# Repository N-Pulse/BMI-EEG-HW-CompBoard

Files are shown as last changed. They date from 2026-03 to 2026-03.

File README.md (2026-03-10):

# EEG Headset Main Board

This repository contains the PCB design of the EEG main board, adapted from the EMG bracelet's main board, for signal acquisition.
Detailed description of the project can be found in the Documentation folder

This work is licensed under a <a rel="license" href="https://creativecommons.org/licenses/by/4.0/">Creative Commons Attribution 4.0 International License</a>.

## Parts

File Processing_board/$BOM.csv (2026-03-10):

Reference | Qty | Value | DNP | Exclude from Board | MANUFACTURER | Manufacturer_Part_Number | Link
AE1 | 1 | PCB_antenna |  | Exclure du PCB
AE2 | 1 | AMCA31-2R450G-S1F-T3 |  |  | ABRACON | AMCA31-2R450G-S1F-T3 | https://www.mouser.ch/ProductDetail/ABRACON/AMCA31-2R450G-S1F-T3?qs=AAveGqk956GLuOddQEK40Q%3D%3D
C1,C2,C28,C30,C40,C41,C42,C43,C45,C46,C47,C51 | 12 | 100nF |  |  | Samsung Electro-Mechanics | CL05B104KP5VPNC | https://eu.mouser.com/ProductDetail/Samsung-Electro-Mechanics/CL05B104KP5VPNC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
C3,C4 | 2 | 10pF |  |  | KYOCERA AVX | 0603ZC100KAT2A | https://www.mouser.ch/ProductDetail/KYOCERA-AVX/0603ZC100KAT2A?qs=jGANiKWBgcibzoGXAkKY5Q%3D%3D
C5,C13 | 2 | 100μF
C6,C12 | 2 | >10μF
C7,C8,C10,C14,C15,C16,C17,C18,C19,C20,C21,C22,C23,C24 | 14 | 1μF
C9,C11 | 2 | 0.1μF
C25,C26,C27,C56,C57,C58,C59,C60,C61,C62,C63,C64,C65,C66,C67,C68 | 16 | 10nF
C29,C31,C50,C52 | 4 | 10uF |  |  | Murata Electronics | GRM155R61A106ME11D | https://www.mouser.ch/ProductDetail/Murata-Electronics/GRM155R61A106ME11D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
C34 | 1 | 0.8pF |  |  | Murata Electronics | GRM1555C1HR80BA01D | https://www.mouser.ch/ProductDetail/Murata-Electronics/GRM1555C1HR80BA01D?qs=e%252BE4OD6MgMezPYPintwvrA%3D%3D
C35 | 1 | 0.3pF |  |  | Murata Electronics | GRM1555C1HR30WA01D | https://www.mouser.ch/ProductDetail/Murata-Electronics/GRM1555C1HR30WA01D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
C38 | 1 | 1.5pF |  |  | Walsin | 0402N1R5B100CT | https://www.mouser.ch/ProductDetail/Walsin/0402N1R5B100CT?qs=ZrPdAQfJ6DObCBhS8paADQ%3D%3D
C44 | 1 | 1uF |  |  | Samsung Electro-Mechanics | CL05A105KP5NNNC | https://www.mouser.ch/ProductDetail/Samsung-Electro-Mechanics/CL05A105KP5NNNC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
C48 | 1 | 470nF |  |  | KEMET | C0402C473K8RACAUTO7411 | https://www.mouser.ch/ProductDetail/KEMET/C0402C473K8RACAUTO7411?qs=sSYV1F9c5cEF%2FA7Et64KMA%3D%3D
C49 | 1 | 4.7uF |  |  | Murata Electronics | GRM155C61E475ME15D | https://www.digikey.ch/en/products/detail/murata-electronics/GRM155C61E475ME15D/16821133
C53,C54 | 2 | 27pF |  |  | KYOCERA AVX | 08055C270KAT2A | https://www.mouser.ch/ProductDetail/KYOCERA-AVX/08055C270KAT2A?qs=ykEKLGTiBcy%2FccVg1dGO5g%3D%3D
C55 | 1 | 220nF |  |  | Murata Electronics | GRT155R71A224KE01D | https://www.mouser.ch/ProductDetail/Murata-Electronics/GRT155R71A224KE01D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
C69 | 1 | 1nF
D1,D4,D5,D6 | 4 | IN_S42BT LED |  |  | Inolux | IN-S42BT5G | https://www.mouser.ch/ProductDetail/Inolux/IN-S42BT5G?qs=mAH9sUMRCttW6d2tLN392Q%3D%3D
D2,D3 | 2 | PMEG4030AEXE-QX |  |  | Nexperia | PMEG4030AEXE-QX | https://www.mouser.ch/ProductDetail/Nexperia/PMEG4030AEXE-QX?qs=olJun0bQHM9XKv%2FbcqOajw%3D%3D
FL1 | 1 | DLF162500LT-5028A1 |  |  | TDK | DLF162500LT-5028A1 | https://www.mouser.ch/ProductDetail/TDK/DLF162500LT-5028A1?qs=U%2FZX79kHR%2FlwIbAISCs3qA%3D%3D
H1,H2 | 2 | MountingHole |  | Exclure du PCB
J1,J2 | 2 | Conn_01x08_Pin
J3 | 1 | Conn_01x06_Pin
J4,J5,J8,J9 | 4 | Conn_01x03_Pin
J6 | 1 | Conn_01x02_Pin
J10 | 1 | CONMHF1-SMD-G-T |  |  | TE Connectivity / Linx Technologies | CONMHF1-SMD-G-T | https://www.mouser.ch/ProductDetail/TE-Connectivity-Linx-Technologies/CONMHF1-SMD-G-T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
J11 | 1 | USB4215-03-A_REVA |  |  | CGT | USB4215-03-A | https://www.mouser.ch/ProductDetail/GCT/USB4215-03-A?qs=IKkN%2F947nfBipec8wvDabA%3D%3D
J12 | 1 | Conn_01x02_Pin
JP1 | 1 | SolderJumper_2_Bridged
JP2 | 1 | SolderJumper_2_Open
L1 | 1 | 2.7nH |  |  | Murata Electronics | LQG15HS2N7S02D | https://www.mouser.ch/ProductDetail/Murata-Electronics/LQG15HS2N7S02D?qs=ctz47l0uL1AKrLI74yO5Qw%3D%3D
L2 | 1 | 3.9nH |  |  | TE Connectivity / Sigma Inductors | 36550402S3N9T | https://www.mouser.ch/ProductDetail/TE-Connectivity-Sigma-Inductors/36550402S3N9T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
L3 | 1 | 2.2uH |  |  | Wurth Elektronik | 74479774222 | https://www.mouser.ch/ProductDetail/Wurth-Elektronik/74479774222?qs=%252BUQ4csG8Rsd58%2FKCVoLnRw%3D%3D
Q1 | 1 | DMP3056LSS-13 |  |  | Diodes Incorporated | DMP3056LSS-13 | https://www.mouser.ch/ProductDetail/Diodes-Incorporated/DMP3056LSS-13?qs=oUsD4qhOtFyEnPLZKitYRA%3D%3D
Q2,Q3 | 2 | DMN66D0LT-7 |  |  | Diodes Incorporated | DMN66D0LT-7 | https://www.mouser.ch/ProductDetail/Diodes-Incorporated/DMN66D0LT-7?qs=ptj1V1atRApcnSIo%2FSL0QQ%3D%3D
R1,R2,R3,R4,R7,R8,R10,R14,R20 | 9 | 100R |  |  | KOA Speer | RK73B1ETTPD101J | https://www.mouser.ch/ProductDetail/KOA-Speer/RK73B1ETTPD101J?qs=7ZBenkSduJQ3N2lLjwh2jA%3D%3D
R5,R6,R9,R13,R17,R18,R19,R21 | 8 | 10k |  |  | Wurth Elektronik | 560112110020 | https://www.mouser.ch/ProductDetail/Wurth-Elektronik/560112110020?qs=mELouGlnn3fA8%252B%2F79%2FueqA%3D%3D
R11,R12,R22,R23,R24,R25,R26,R27,R28,R29,R30,R31,R32,R33,R34,R35,R36,R37 | 18 | 47kΩ
R15,R16 | 2 | 5.1k |  |  | YAGEO | AC0402JR-075K1L | https://www.mouser.ch/ProductDetail/YAGEO/AC0402JR-075K1L?qs=ygRr%2Ftkhtev1AbJgasJMAQ%3D%3D
R38 | 1 | 1MΩ
SW1,SW2 | 2 | TL3305BF100QG |  |  | E-Switch | TL3305BF100QG | https://www.mouser.ch/ProductDetail/E-Switch/TL3305BF100QG?qs=IKkN%2F947nfDIPwqPQja%252BvQ%3D%3D
TP2,TP11 | 2 | TestPoint |  | Exclure du PCB
TP9 | 1 | 5V |  | Exclure du PCB
TP10 | 1 | 5V- |  | Exclure du PCB
TP12,TP13 | 2 | PN5260 |  |  | Keystone | 5260 | https://www.mouser.ch/ProductDetail/Keystone-Electronics/5260?qs=W%2FMpXkg%252BdQ5ZyD03UfNp6A%3D%3D
U1 | 1 | STM32WBA63CIU6 |  |  | STMicroelectronics | STM32WBA63CIU6 | https://www.mouser.ch/ProductDetail/STMicroelectronics/STM32WBA63CIU6?qs=a2MtRaTmNORvrgIwkIejkg%3D%3D
U5 | 1 | LD1117S50TR_SOT223 |  |  | STMicroelectronics | LD1117S50TR | https://www.mouser.ch/ProductDetail/STMicroelectronics/LD1117S50TR?qs=eQN2Ig5lfEwsh0kTXN%2FkTg%3D%3D
U6 | 1 | LD1117S33TR_SOT223 |  |  | STMicroelectronics | LD1117S33TR | https://www.mouser.ch/ProductDetail/STMicroelectronics/LD1117S33TR?qs=edoyzKMbmhntQZx4BFmoqw%3D%3D
U8 | 1 | BGS13SN8E6327XTSA1 |  |  | Infineon Technologies | BGS13SN8E6327XTSA1 | https://www.mouser.ch/ProductDetail/Infineon-Technologies/BGS13SN8E6327XTSA1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
U9 | 1 | MCP2200-I_SO |  |  | Microchip Technology | MCP2200-I/SO | https://www.mouser.ch/ProductDetail/Microchip-Technology/MCP2200-I-SO?qs=kI7nsUnms46fN8L9VZlJCA%3D%3D
U10,U11 | 2 | ADS1299IPAG
XTAL1 | 1 | CX2016DB32000D0FLJCC |  |  | KYOCERA AVX | CX2016DB32000D0FLJCC | https://www.mouser.ch/ProductDetail/KYOCERA-AVX/CX2016DB32000D0FLJCC?qs=k8ubvZJoN9AkB0G5%2Fsjh3g%3D%3D
XTAL2 | 1 | ECS-120-18-5PX-CKM-TR |  |  | ECS | ECS-120-18-5PX-CKM-TR | https://www.mouser.ch/ProductDetail/ECS/ECS-120-18-5PX-CKM-TR?qs=7MVldsJ5UaxGiQ3V9H8iDw%3D%3D
C36,C37 | 2 | Unknown | DNP | Exclure du PCB
C39 | 1 | 1.5pF | DNP | Exclure du PCB

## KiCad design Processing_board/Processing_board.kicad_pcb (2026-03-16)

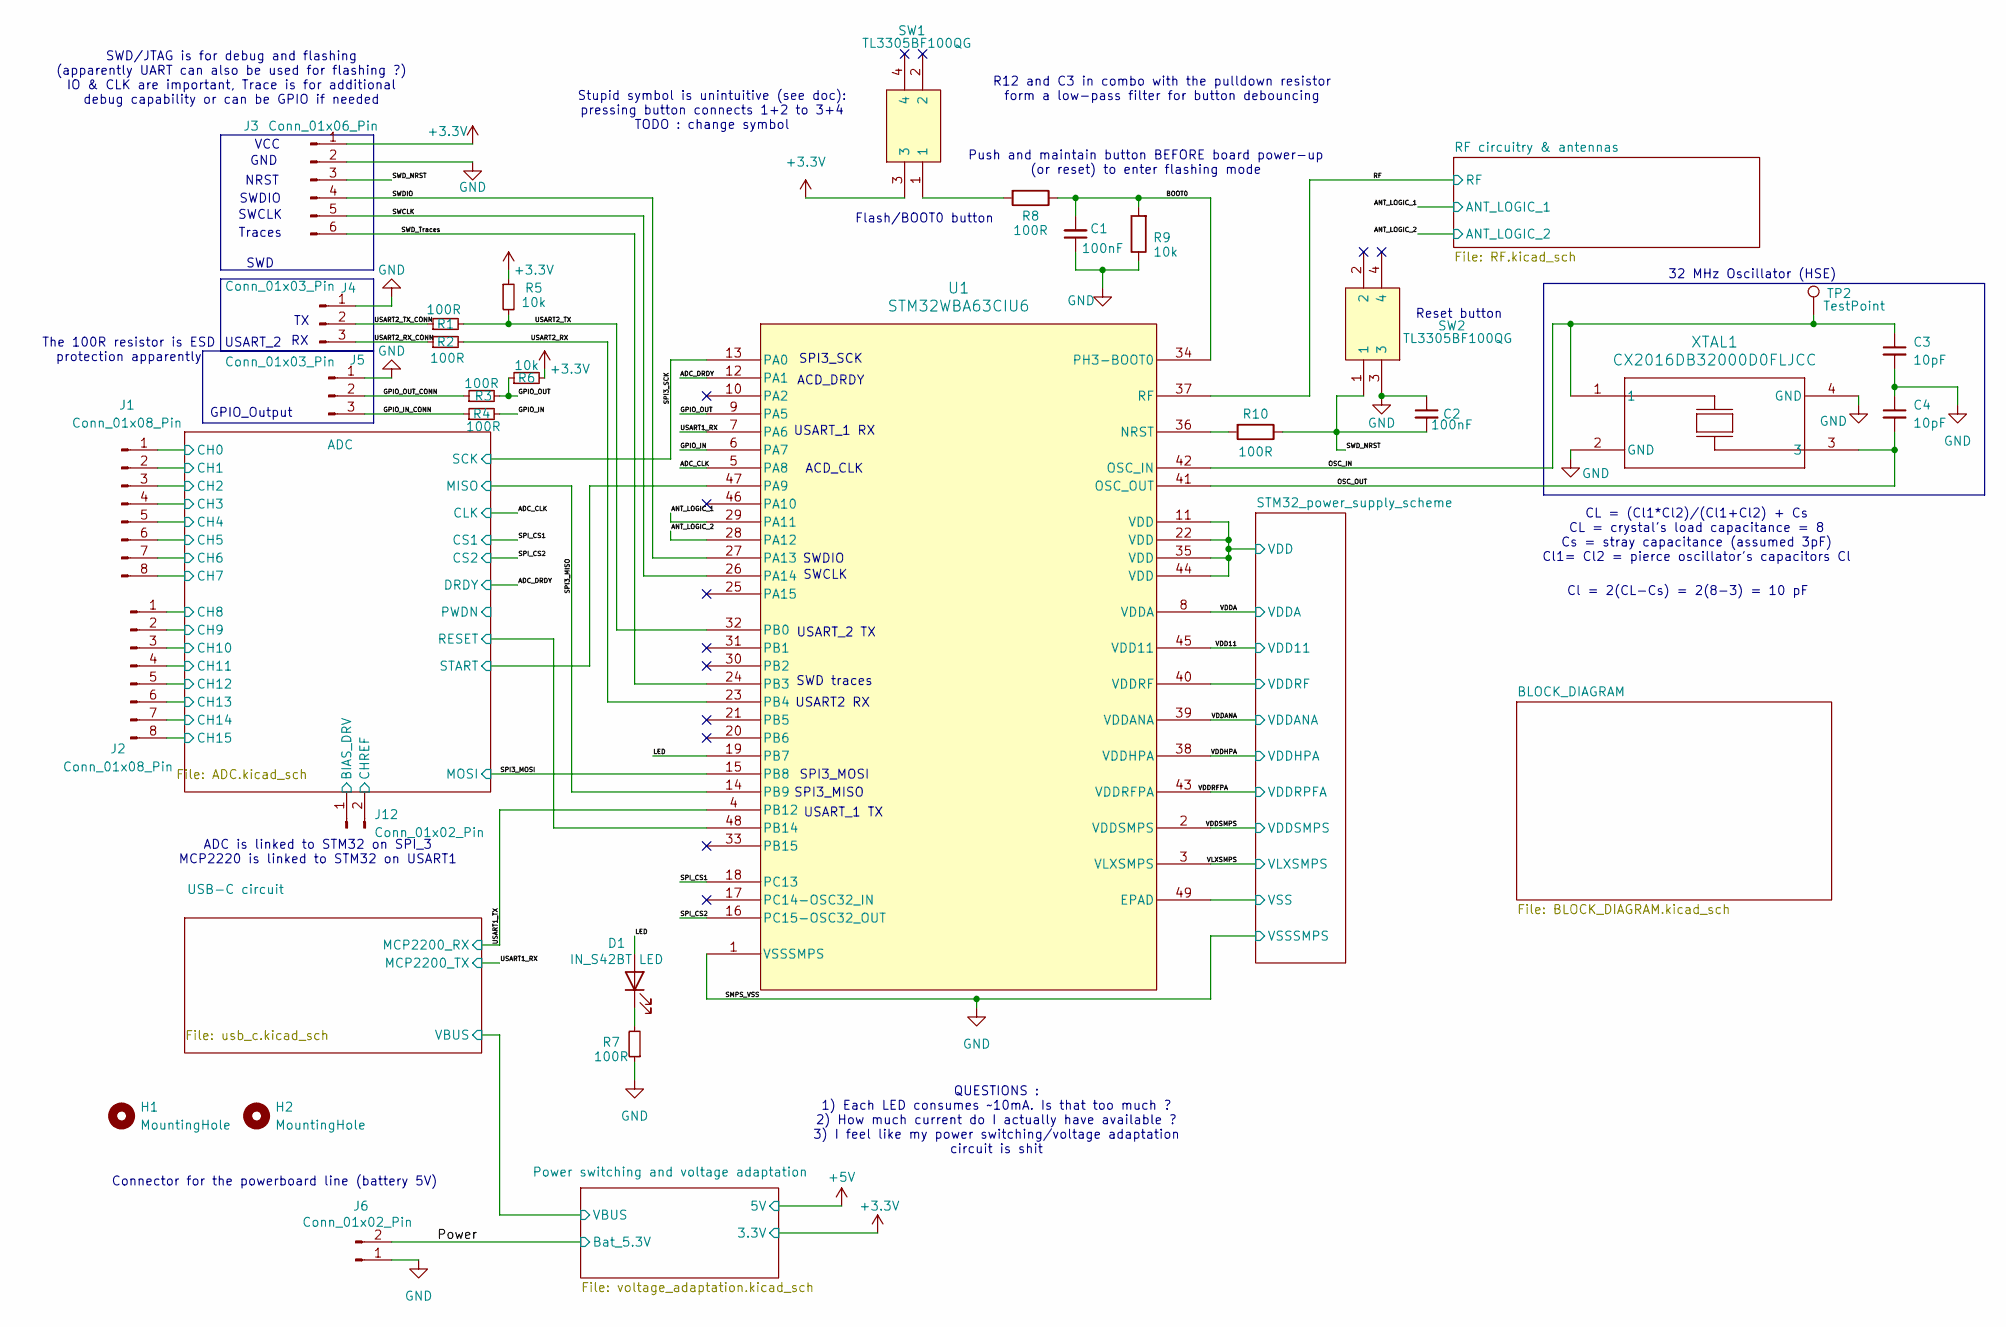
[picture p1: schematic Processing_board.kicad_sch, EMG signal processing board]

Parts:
C1, C2: 100nF; C_0201_0603Metric_Pad0.64x0.40mm_HandSolder; Manufacturer_Part_Number CL05B104KP5VPNC
C3, C4: 10pF; C_0201_0603Metric_Pad0.64x0.40mm_HandSolder; Manufacturer_Part_Number 0603ZC100KAT2A
D1: IN_S42BT LED; LED_0402_1005Metric; Manufacturer_Part_Number IN-S42BT5G
H1, H2: MountingHole; MountingHole_2.2mm_M2
J1, J2: Conn_01x08_Pin; PinSocket_1x08_P2.54mm_Vertical
J3: Conn_01x06_Pin; PinSocket_1x06_P2.54mm_Vertical
J4, J5: Conn_01x03_Pin; PinSocket_1x03_P2.54mm_Vertical
J6, J12: Conn_01x02_Pin; PinSocket_1x02_P2.54mm_Vertical
R1, R2, R3, R4, R7, R8, R10: 100R; R_0402_1005Metric; Manufacturer_Part_Number RK73B1ETTPD101J
R5, R6, R9: 10k; R_0402_1005Metric; Manufacturer_Part_Number 560112110020
SW1, SW2: TL3305BF100QG; TL3305BF160QG; Mouser Part Number 612-TL3305BF100QG
TP2: TestPoint; TestPoint_Pad_D1.0mm
U1: STM32WBA63CIU6; UFQFPN-48_STM; Manufacturer_Part_Number STM32WBA63CIU6
XTAL1: CX2016DB32000D0FLJCC; xtal4_CX2016DB_AVX; Manufacturer_Part_Number CX2016DB32000D0FLJCC

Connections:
+3.3V: J3.1, R5.1, R6.2, SW1.3, U1.2 (VDDSMPS), U1.8 (VDDA), U1.11 (VDD), U1.22 (VDD), U1.35 (VDD), U1.40 (VDDRF), U1.44 (VDD); also elsewhere on the board
/ADC/BIAS_DRV: J12.1; also elsewhere on the board
/ADC/IN1P: J1.1; also elsewhere on the board
/ADC/IN2P: J1.2; also elsewhere on the board
/ADC/IN3P: J1.3; also elsewhere on the board
/ADC/IN4P: J1.4; also elsewhere on the board
/ADC/IN5P: J1.5; also elsewhere on the board
/ADC/IN6P: J1.6; also elsewhere on the board
/ADC/IN7P: J1.7; also elsewhere on the board
/ADC/IN8P: J1.8; also elsewhere on the board
/ADC/IN9P: J2.1; also elsewhere on the board
/ADC/IN10P: J2.2; also elsewhere on the board
/ADC/IN11P: J2.3; also elsewhere on the board
/ADC/IN12P: J2.4; also elsewhere on the board
/ADC/IN13P: J2.5; also elsewhere on the board
/ADC/IN14P: J2.6; also elsewhere on the board
/ADC/IN15P: J2.7; also elsewhere on the board
/ADC/IN16P: J2.8; also elsewhere on the board
/ADC/RESET: U1.48 (PB14); also elsewhere on the board
/ADC/SRB1: J12.2; also elsewhere on the board
/ADC/START: U1.47 (PA9); also elsewhere on the board
/ADC_CLK: U1.5 (PA8); also elsewhere on the board
/ADC_DRDY: U1.12 (PA1); also elsewhere on the board
/ANT_LOGIC_1: U1.29 (PA11)
/ANT_LOGIC_2: U1.28 (PA12)
/BOOT0: C1.2, R8.1, R9.2, U1.34 (PH3-BOOT0)
/GPIO_IN: R4.2, U1.6 (PA7)
/GPIO_IN_CONN: J5.3, R4.1
/GPIO_OUT: R3.2, R6.1, U1.9 (PA5)
/GPIO_OUT_CONN: J5.2, R3.1
/LED: D1.2 (A), U1.19 (PB7)
/OSC_IN: C3.1, TP2.1, U1.42 (OSC_IN), XTAL1.1
/OSC_OUT: C4.2, U1.41 (OSC_OUT), XTAL1.3
/Power: J6.2; also elsewhere on the board
/RF: U1.37 (RF); also elsewhere on the board
/SPI3_MISO: U1.14 (PB9); also elsewhere on the board
/SPI3_MOSI: U1.15 (PB8); also elsewhere on the board
/SPI3_SCK: U1.13 (PA0); also elsewhere on the board
/SPI_CS1: U1.18 (PC13); also elsewhere on the board
/SPI_CS2: U1.16 (PC15-OSC32_OUT); also elsewhere on the board
/SWCLK: J3.5, U1.26 (PA14)
/SWDIO: J3.4, U1.27 (PA13)
/SWD_NRST: C2.2, J3.3, R10.1, SW2.1
/SWD_Traces: J3.6, U1.24 (PB3)
/USART1_RX: U1.7 (PA6); also elsewhere on the board
/USART1_TX: U1.4 (PB12); also elsewhere on the board
/USART2_RX: R2.2, U1.23 (PB4)
/USART2_RX_CONN: J4.3, R2.1
/USART2_TX: R1.2, R5.2, U1.32 (PB0)
/USART2_TX_CONN: J4.2, R1.1
/VDD11: U1.39 (VDDANA), U1.43 (VDDRFPA), U1.45 (VDD11); also elsewhere on the board
/VDDHPA: U1.38 (VDDHPA); also elsewhere on the board
/VLXSMPS: U1.3 (VLXSMPS); also elsewhere on the board
GND: C1.1, C2.1, C3.2, C4.1, J3.2, J4.1, J5.1, J6.1, R7.1, R9.1, SW2.3, U1.1 (VSSSMPS), U1.49 (EPAD), XTAL1.2 (GND), XTAL1.4 (GND); also elsewhere on the board
unnamed: D1.1 (K), R7.2
unnamed: R8.2, SW1.1
unnamed: R10.2, U1.36 (NRST)

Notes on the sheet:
USART_1 TX
SWD/JTAG is for debug and flashing (apparently UART can also be used for flashing ?) IO & CLK are important, Trace is for additional debug capability or can be GPIO if needed
SWD
VCC
SPI3_MISO
The 100R resistor is ESD protection apparently
Reset button
32 MHz Oscillator (HSE)
SWCLK
SPI3_MOSI
SPI3_SCK
Flash/BOOT0 button
CL = (Cl1*Cl2)/(Cl1+Cl2) + Cs CL = crystal's load capacitance = 8 Cs = stray capacitance (assumed 3pF) Cl1= Cl2 = pierce oscillator's capacitors Cl
Stupid symbol is unintuitive (see doc): pressing button connects 1+2 to 3+4 TODO : change symbol
Push and maintain button BEFORE board power-up (or reset) to enter flashing mode
NRST
SWDIO
ADC is linked to STM32 on SPI_3 MCP2220 is linked to STM32 on USART1
USART_2 TX
USART_2
ACD_DRDY
ACD_CLK
Traces
USART_1 RX
GPIO_Output
QUESTIONS : 1) Each LED consumes ~10mA. Is that too much ? 2) How much current do I actually have available ? 3) I feel like my power switching/voltage adaptation circuit is shit
USART2 RX
Cl = 2(CL-Cs) = 2(8-3) = 10 pF
GND
R12 and C3 in combo with the pulldown resistor form a low-pass filter for button debouncing
Connector for the powerboard line (battery 5V)
SWD traces

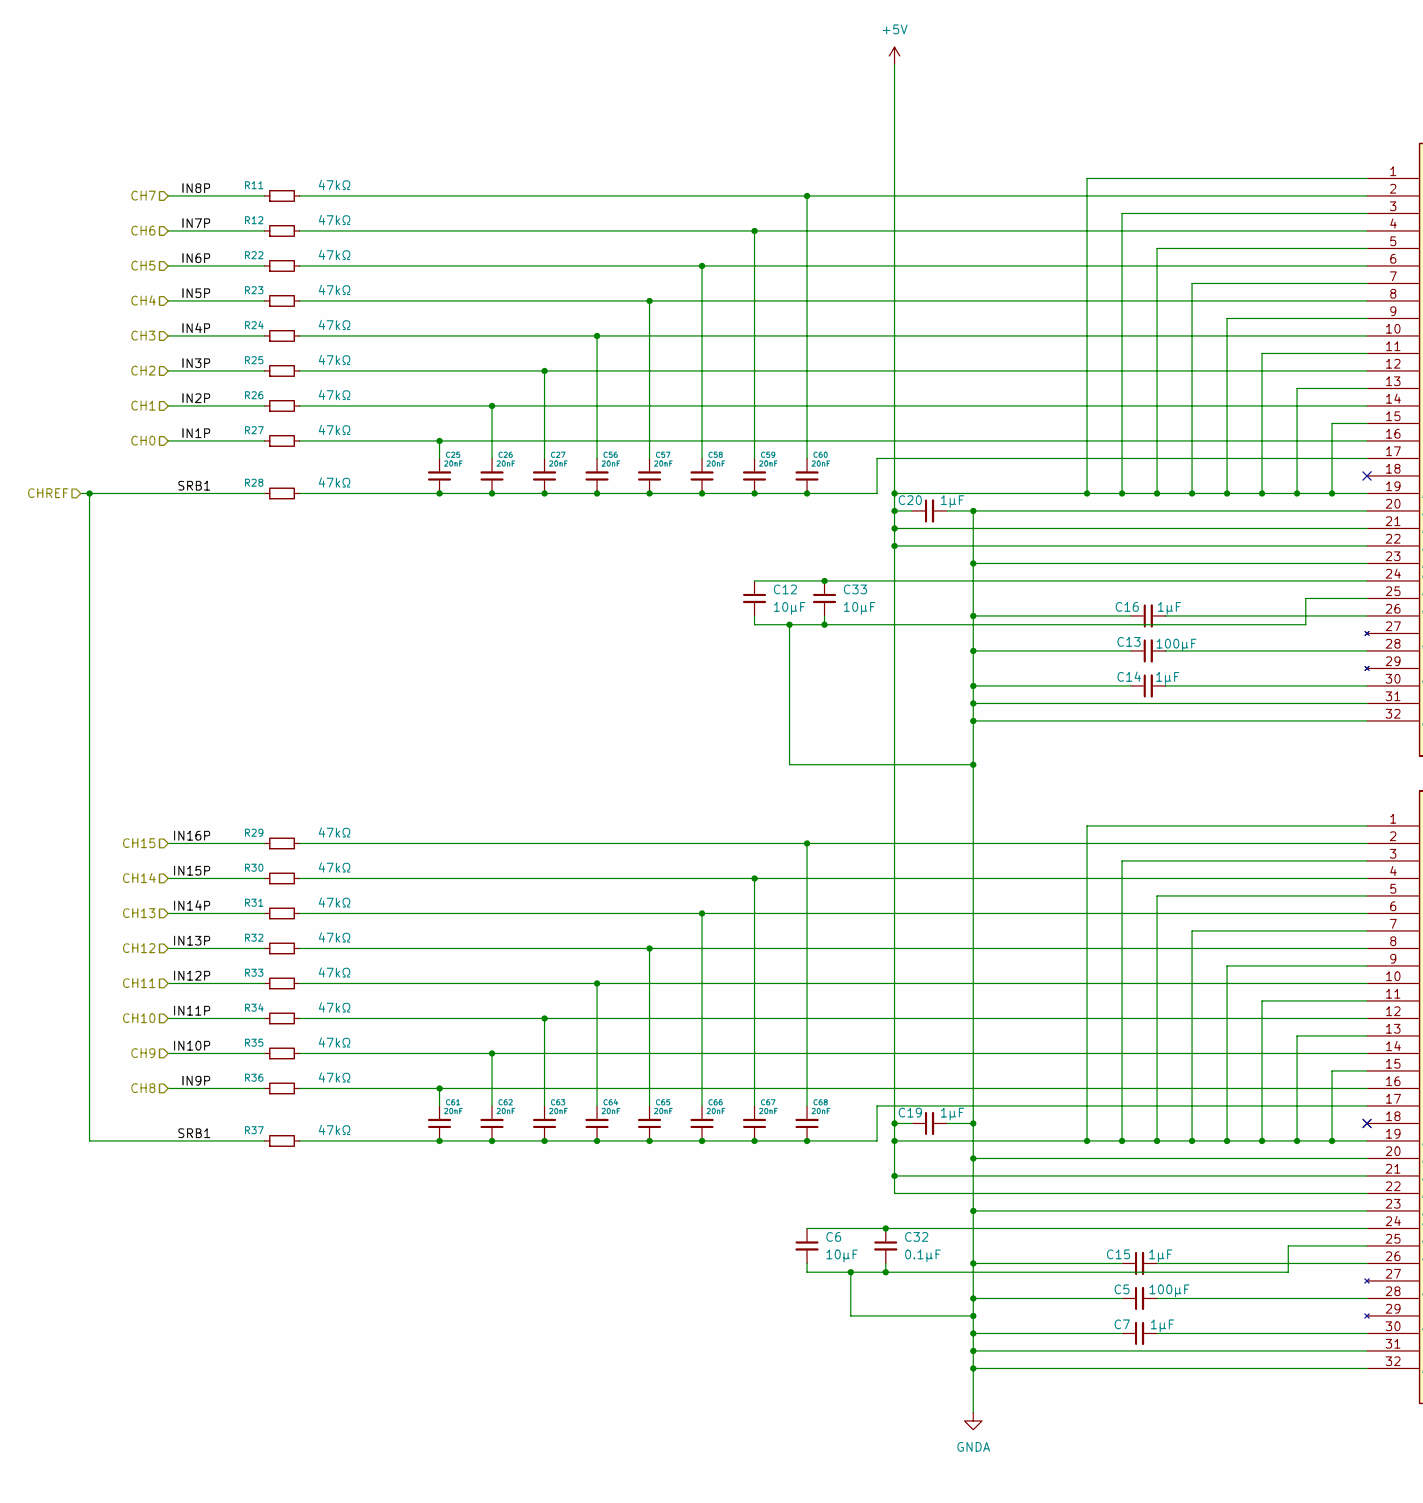
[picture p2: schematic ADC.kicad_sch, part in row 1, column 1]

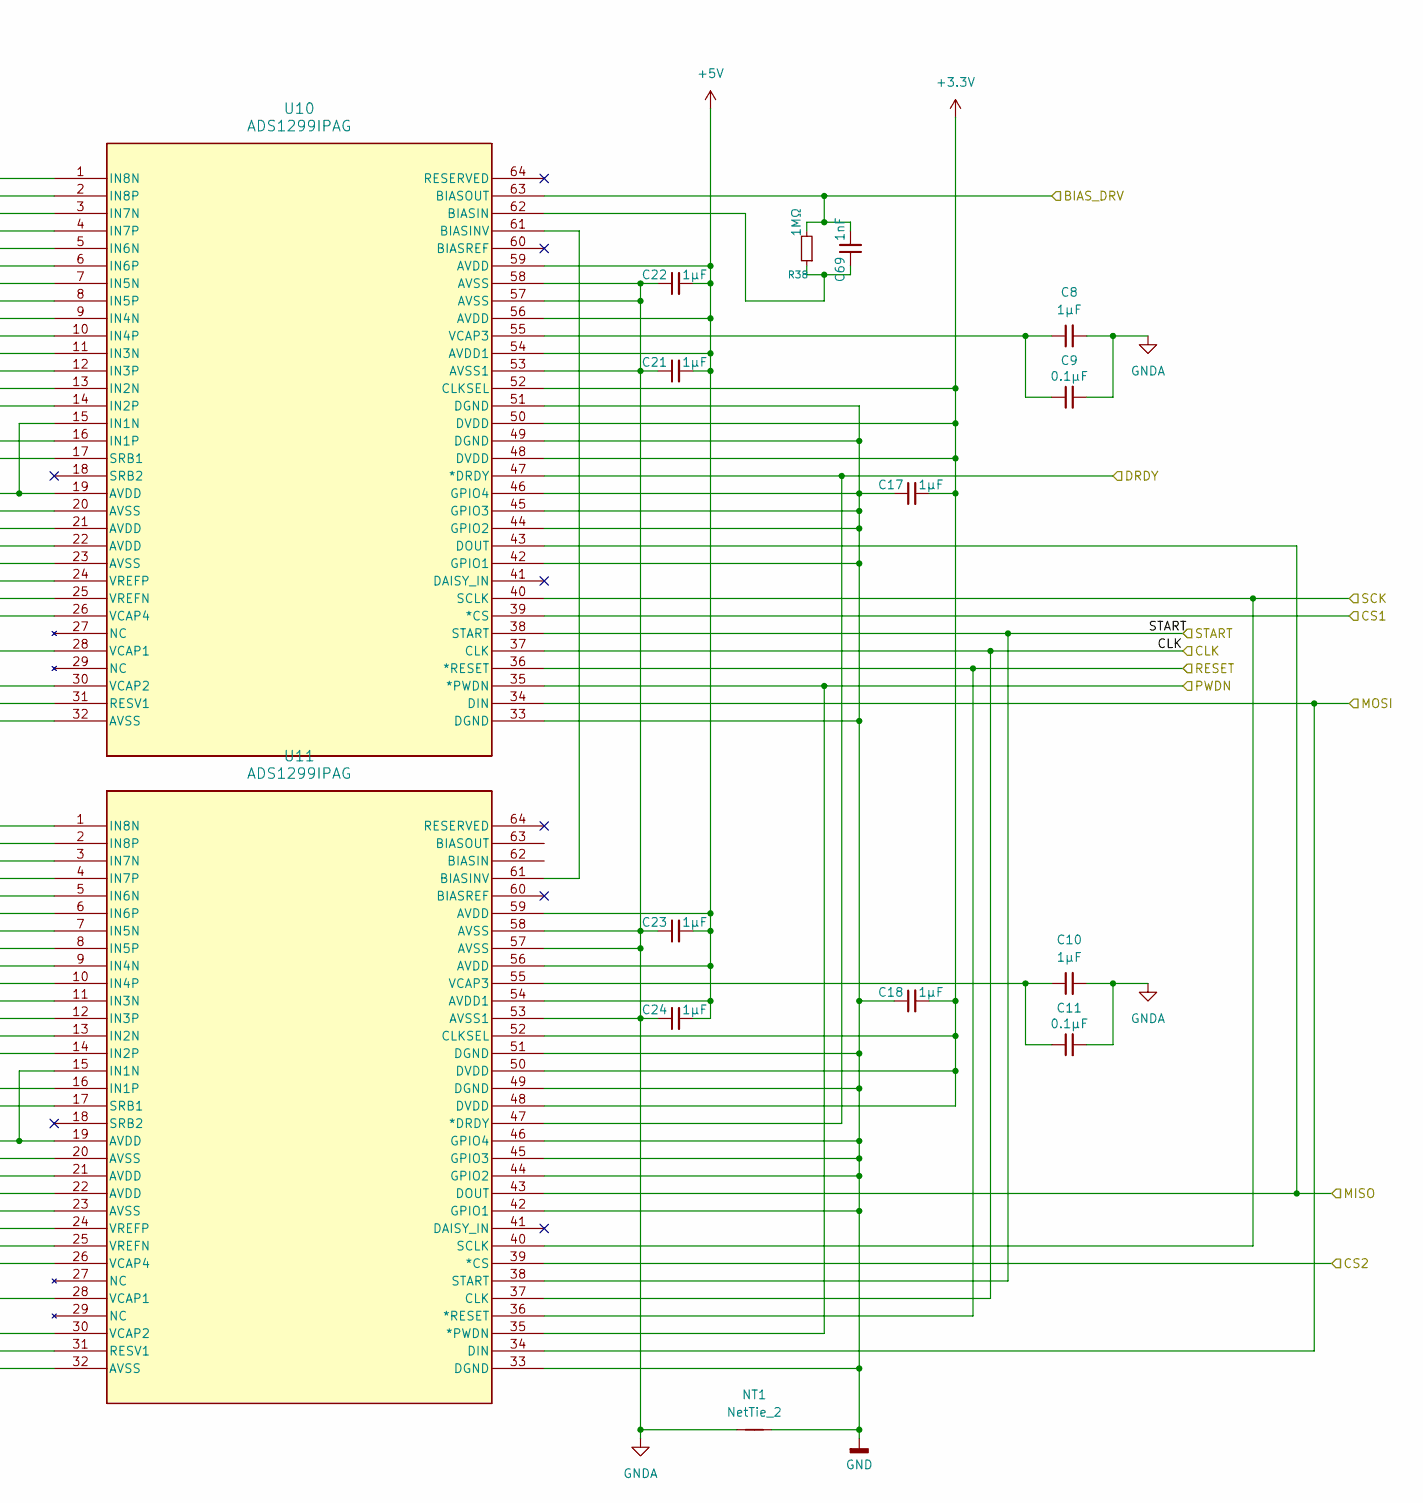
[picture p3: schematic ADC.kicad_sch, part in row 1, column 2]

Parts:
C5, C13: 100μF; C_1210_3225Metric
C6, C12, C33: 10μF; C_0805_2012Metric
C7, C8, C10, C14, C15, C16, C17, C18, C19, C20, C21, C22, C23, C24: 1μF; C_0805_2012Metric
C9, C11: 0.1μF; C_0603_1608Metric
C25, C26, C27, C56, C57, C58, C59, C60, C61, C62, C63, C64, C65, C66, C67, C68: 20nF; C_0603_1608Metric
C32: 0.1µF
C69: 1nF; C_0603_1608Metric
NT1: NetTie_2; NetTie-2_SMD_Pad0.5mm
R11, R12, R22, R23, R24, R25, R26, R27, R28, R29, R30, R31, R32, R33, R34, R35, R36, R37: 47kΩ; R_0603_1608Metric
R38: 1MΩ; R_0603_1608Metric
U10, U11: ADS1299IPAG; ADS1299_PAG64

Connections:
+3.3V: C17.2, C18.2, U10.48 (DVDD), U10.50 (DVDD), U10.52 (CLKSEL), U11.48 (DVDD), U11.50 (DVDD), U11.52 (CLKSEL); also elsewhere on the board
+5V: C19.1, C20.1, C21.2, C22.2, C23.2, C24.2, U10.1 (IN8N), U10.3 (IN7N), U10.5 (IN6N), U10.7 (IN5N), U10.9 (IN4N), U10.11 (IN3N), U10.13 (IN2N), U10.15 (IN1N), U10.19 (AVDD), U10.21 (AVDD), U10.22 (AVDD), U10.54 (AVDD1), U10.56 (AVDD), U10.59 (AVDD), U11.1 (IN8N), U11.3 (IN7N), U11.5 (IN6N), U11.7 (IN5N), U11.9 (IN4N), U11.11 (IN3N), U11.13 (IN2N), U11.15 (IN1N), U11.19 (AVDD), U11.21 (AVDD), U11.22 (AVDD), U11.54 (AVDD1), U11.56 (AVDD), U11.59 (AVDD); also elsewhere on the board
/ADC/BIAS_DRV: C69.2, R38.2, U10.63 (BIASOUT); also elsewhere on the board
/ADC/IN1P: R27.1; also elsewhere on the board
/ADC/IN2P: R26.1; also elsewhere on the board
/ADC/IN3P: R25.1; also elsewhere on the board
/ADC/IN4P: R24.1; also elsewhere on the board
/ADC/IN5P: R23.1; also elsewhere on the board
/ADC/IN6P: R22.1; also elsewhere on the board
/ADC/IN7P: R12.1; also elsewhere on the board
/ADC/IN8P: R11.1; also elsewhere on the board
/ADC/IN9P: R36.1; also elsewhere on the board
/ADC/IN10P: R35.1; also elsewhere on the board
/ADC/IN11P: R34.1; also elsewhere on the board
/ADC/IN12P: R33.1; also elsewhere on the board
/ADC/IN13P: R32.1; also elsewhere on the board
/ADC/IN14P: R31.1; also elsewhere on the board
/ADC/IN15P: R30.1; also elsewhere on the board
/ADC/IN16P: R29.1; also elsewhere on the board
/ADC/PWDN: U10.35 (*PWDN), U11.35 (*PWDN)
/ADC/RESET: U10.36 (*RESET), U11.36 (*RESET); also elsewhere on the board
/ADC/SRB1: R28.1, R37.1; also elsewhere on the board
/ADC/START: U10.38 (START), U11.38 (START); also elsewhere on the board
/ADC_CLK: U10.37 (CLK), U11.37 (CLK); also elsewhere on the board
/ADC_DRDY: U10.47 (*DRDY), U11.47 (*DRDY); also elsewhere on the board
/SPI3_MISO: U10.43 (DOUT), U11.43 (DOUT); also elsewhere on the board
/SPI3_MOSI: U10.34 (DIN), U11.34 (DIN); also elsewhere on the board
/SPI3_SCK: U10.40 (SCLK), U11.40 (SCLK); also elsewhere on the board
/SPI_CS1: U10.39 (*CS); also elsewhere on the board
/SPI_CS2: U11.39 (*CS); also elsewhere on the board
GND: C17.1, C18.1, NT1.2, U10.33 (DGND), U10.42 (GPIO1), U10.44 (GPIO2), U10.45 (GPIO3), U10.46 (GPIO4), U10.49 (DGND), U10.51 (DGND), U11.33 (DGND), U11.42 (GPIO1), U11.44 (GPIO2), U11.45 (GPIO3), U11.46 (GPIO4), U11.49 (DGND), U11.51 (DGND); also elsewhere on the board
GNDA: C5.1, C6.2, C7.1, C8.2, C9.2, C10.2, C11.2, C12.2, C13.1, C14.1, C15.1, C16.1, C19.2, C20.2, C21.1, C22.1, C23.1, C24.1, C32.2, C33.2, NT1.1, U10.20 (AVSS), U10.23 (AVSS), U10.25 (VREFN), U10.31 (RESV1), U10.32 (AVSS), U10.53 (AVSS1), U10.57 (AVSS), U10.58 (AVSS), U11.20 (AVSS), U11.23 (AVSS), U11.25 (VREFN), U11.31 (RESV1), U11.32 (AVSS), U11.53 (AVSS1), U11.57 (AVSS), U11.58 (AVSS)
unnamed: C69.1, R38.1, U10.62 (BIASIN)
unnamed: U10.61 (BIASINV), U11.61 (BIASINV)
unnamed: C25.2, R27.2, U10.16 (IN1P)
unnamed: C26.2, R26.2, U10.14 (IN2P)
unnamed: C27.2, R25.2, U10.12 (IN3P)
unnamed: C56.2, R24.2, U10.10 (IN4P)
unnamed: C57.2, R23.2, U10.8 (IN5P)
unnamed: C58.2, R22.2, U10.6 (IN6P)
unnamed: C59.2, R12.2, U10.4 (IN7P)
unnamed: C60.2, R11.2, U10.2 (IN8P)
unnamed: C25.1, C26.1, C27.1, C56.1, C57.1, C58.1, C59.1, C60.1, R28.2, U10.17 (SRB1)
unnamed: C13.2, U10.28 (VCAP1)
unnamed: C14.2, U10.30 (VCAP2)
unnamed: C8.1, C9.1, U10.55 (VCAP3)
unnamed: C16.2, U10.26 (VCAP4)
unnamed: C12.1, C33.1, U10.24 (VREFP)
unnamed: C61.2, R36.2, U11.16 (IN1P)
unnamed: C62.2, R35.2, U11.14 (IN2P)
unnamed: C63.2, R34.2, U11.12 (IN3P)
unnamed: C64.2, R33.2, U11.10 (IN4P)
unnamed: C65.2, R32.2, U11.8 (IN5P)
unnamed: C66.2, R31.2, U11.6 (IN6P)
unnamed: C67.2, R30.2, U11.4 (IN7P)
unnamed: C68.2, R29.2, U11.2 (IN8P)
unnamed: C61.1, C62.1, C63.1, C64.1, C65.1, C66.1, C67.1, C68.1, R37.2, U11.17 (SRB1)
unnamed: C5.2, U11.28 (VCAP1)
unnamed: C7.2, U11.30 (VCAP2)
unnamed: C10.1, C11.1, U11.55 (VCAP3)
unnamed: C15.2, U11.26 (VCAP4)
unnamed: C6.1, C32.1, U11.24 (VREFP)

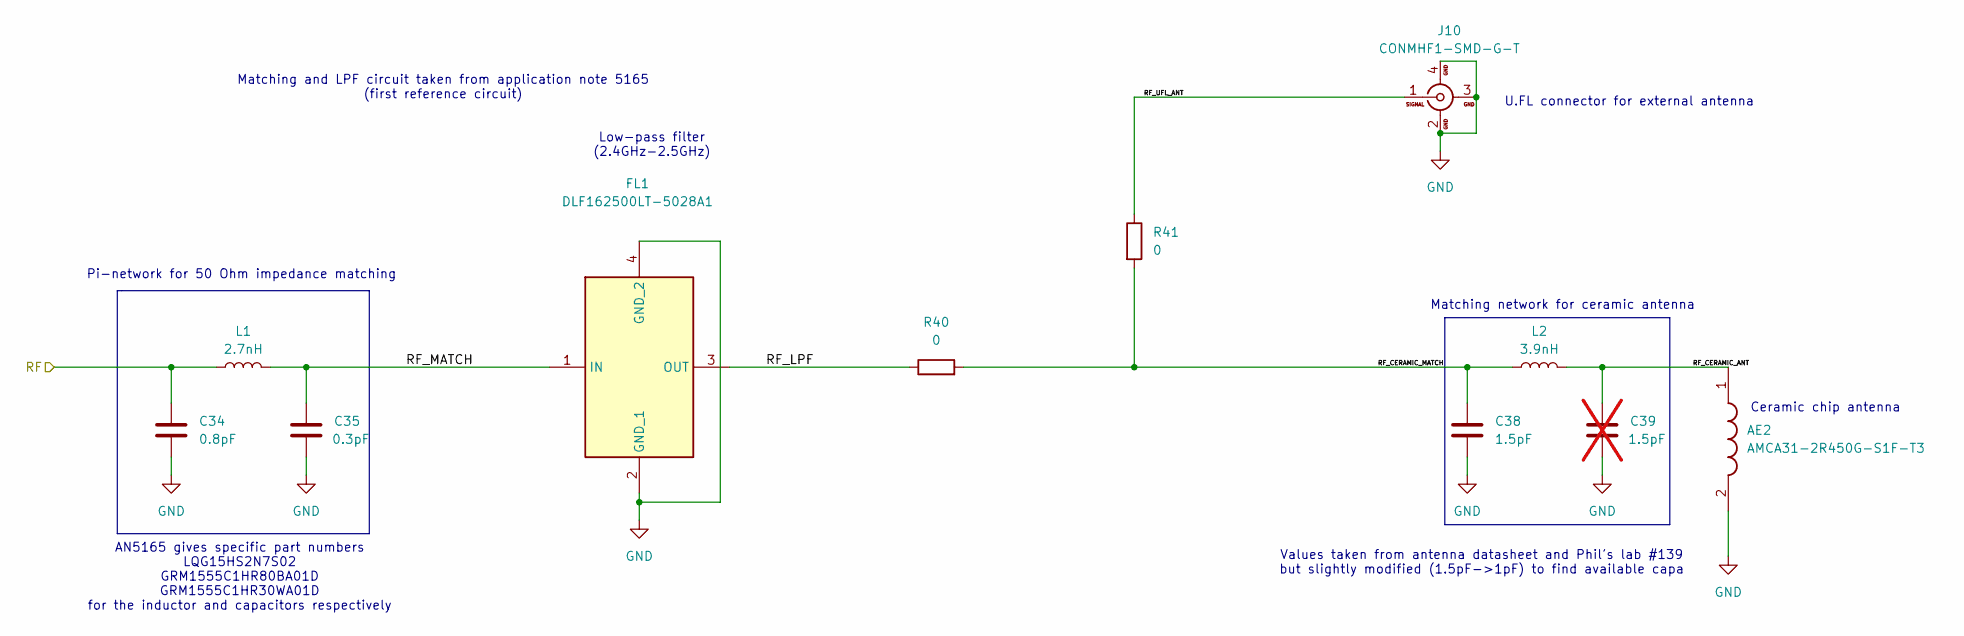
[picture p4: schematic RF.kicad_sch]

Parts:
AE2: AMCA31-2R450G-S1F-T3; ANTC3216X140N; Mouser Part Number 815-CA312R450GS1FT3
C34: 0.8pF; C_0201_0603Metric_Pad0.64x0.40mm_HandSolder; Manufacturer_Part_Number GRM1555C1HR80BA01D
C35: 0.3pF; C_0201_0603Metric_Pad0.64x0.40mm_HandSolder; Manufacturer_Part_Number GRM1555C1HR30WA01D
C38: 1.5pF; C_0201_0603Metric_Pad0.64x0.40mm_HandSolder; Manufacturer_Part_Number 0402N1R5B100CT
C39: 1.5pF; C_0402_1005Metric; not fitted
FL1: DLF162500LT-5028A1; DLF162500LT5028A1; Mouser Part Number 810-DLF16250LT5028A1
J10: CONMHF1-SMD-G-T; CONMHF1SMDGT; Mouser Part Number 712-CONMHF1-SMD-G-T
L1: 2.7nH; L_0402_1005Metric; Manufacturer_Part_Number LQG15HS2N7S02D
L2: 3.9nH; L_0402_1005Metric; Manufacturer_Part_Number 36550402S3N9T
R40, R41: 0; R_0603_1608Metric

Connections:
/RF: C34.1, L1.1; also elsewhere on the board
/RF circuitry & antennas/RF_CERAMIC_ANT: AE2.1 (FEED), C39.1, L2.2
/RF circuitry & antennas/RF_CERAMIC_MATCH: C38.1, L2.1, R40.2, R41.2
/RF circuitry & antennas/RF_LPF: FL1.3 (OUT), R40.1
/RF circuitry & antennas/RF_MATCH: C35.1, FL1.1 (IN), L1.2
/RF circuitry & antennas/RF_UFL_ANT: J10.1, R41.1
GND: AE2.2 (NC), C34.2, C35.2, C38.2, C39.2, FL1.2 (GND_1), FL1.4 (GND_2), J10.2, J10.3, J10.4; also elsewhere on the board

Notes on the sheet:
U.FL connector for external antenna
Pi-network for 50 Ohm impedance matching
Matching and LPF circuit taken from application note 5165 (first reference circuit)
AN5165 gives specific part numbers LQG15HS2N7S02 GRM1555C1HR80BA01D GRM1555C1HR30WA01D for the inductor and capacitors respectively
Ceramic chip antenna
Low-pass filter (2.4GHz-2.5GHz)
Values taken from antenna datasheet and Phil's lab #139 but slightly modified (1.5pF->1pF) to find available capa
Matching network for ceramic antenna

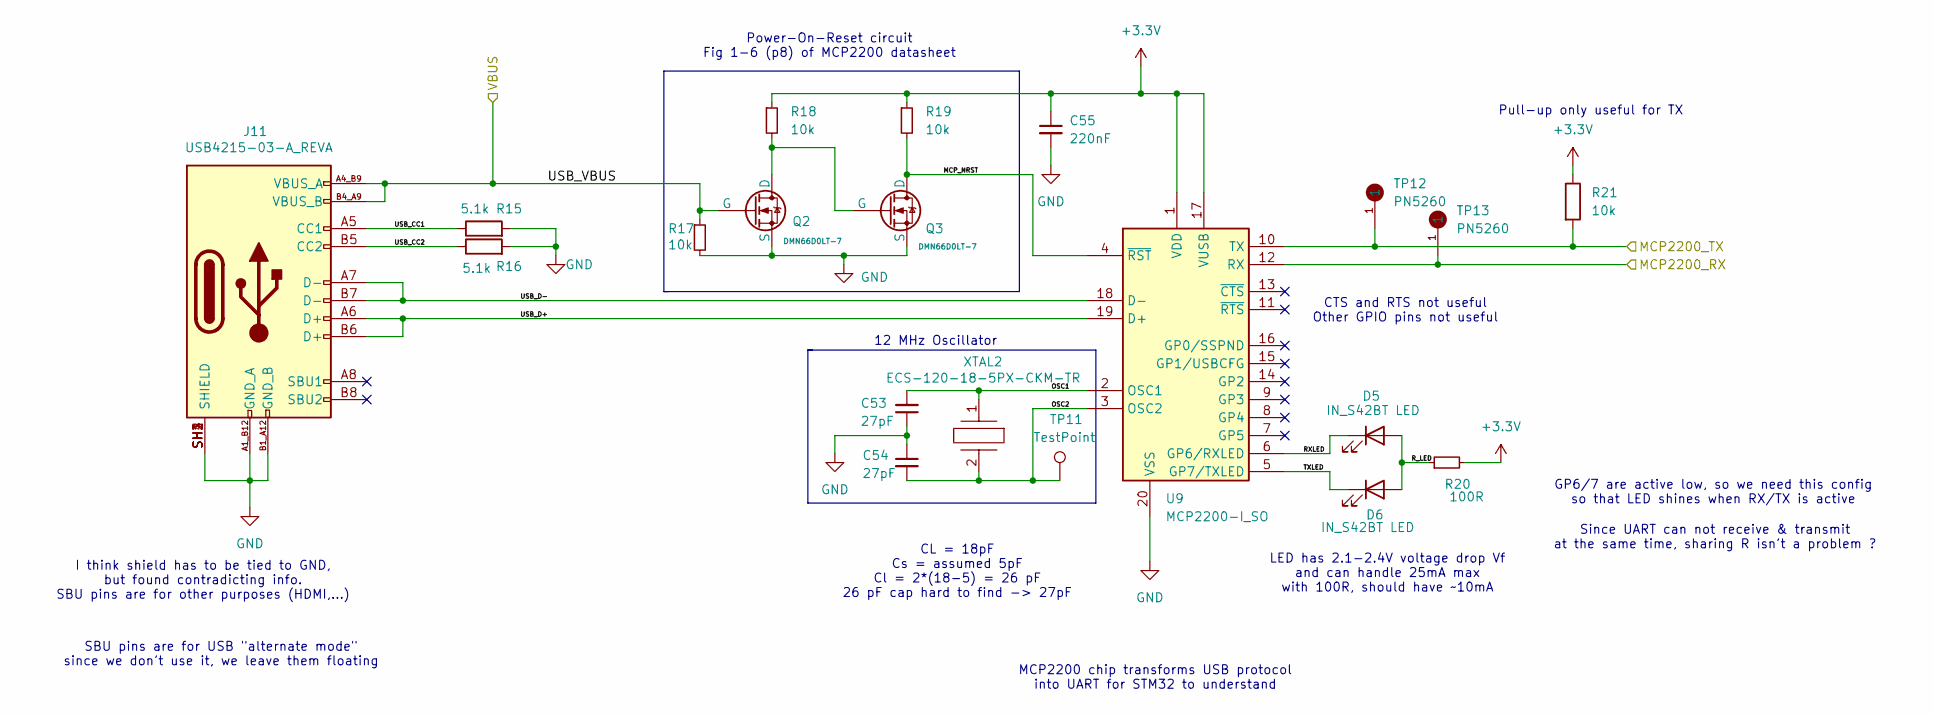
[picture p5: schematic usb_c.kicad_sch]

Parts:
C53, C54: 27pF; C_0201_0603Metric_Pad0.64x0.40mm_HandSolder; Manufacturer_Part_Number 08055C270KAT2A
C55: 220nF; C_0201_0603Metric_Pad0.64x0.40mm_HandSolder; Manufacturer_Part_Number GRT155R71A224KE01D
D5, D6: IN_S42BT LED; LED_0402_1005Metric; Manufacturer_Part_Number IN-S42BT5G
J11: USB4215-03-A_REVA; GCT_USB4215-03-A_REVA; PARTREV A
Q2, Q3: DMN66D0LT-7; SOT50P160X90-3N; Mouser Part Number 621-DMN66D0LT-7
R15, R16: 5.1k; R_0402_1005Metric; Manufacturer_Part_Number AC0402JR-075K1L
R17, R18, R19, R21: 10k; R_0402_1005Metric; Manufacturer_Part_Number 560112110020
R20: 100R; R_0402_1005Metric; Manufacturer_Part_Number RK73B1ETTPD101J
TP11: TestPoint; TestPoint_Pad_D1.0mm
TP12, TP13: PN5260; Manufacturer_Part_Number 5260
U9: MCP2200-I_SO; SOIC127P1030X265-20N; Mouser Part Number 579-MCP2200-I/SO
XTAL2: ECS-120-18-5PX-CKM-TR; ECS120185PXCKMTR; Mouser Part Number 520-ECS120185PXCKMTR

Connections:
+3.3V: C55.1, R18.1, R19.1, R20.2, R21.1, U9.1 (VDD), U9.17 (VUSB); also elsewhere on the board
/USART1_RX: R21.2, TP12.1, U9.10 (TX); also elsewhere on the board
/USART1_TX: TP13.1, U9.12 (RX); also elsewhere on the board
/USB-C circuit/MCP_NRST: Q3.1 (D), R19.2, U9.4 (~RST)
/USB-C circuit/OSC1: C53.2, U9.2 (OSC1), XTAL2.1
/USB-C circuit/OSC2: C54.2, TP11.1, U9.3 (OSC2), XTAL2.2
/USB-C circuit/RXLED: D5.1 (K), U9.6 (GP6/RXLED)
/USB-C circuit/R_LED: D5.2 (A), D6.2 (A), R20.1
/USB-C circuit/TXLED: D6.1 (K), U9.5 (GP7/TXLED)
/USB-C circuit/USB_CC1: J11.A5 (CC1), R15.1
/USB-C circuit/USB_CC2: J11.B5 (CC2), R16.1
/USB-C circuit/USB_D+: J11.A6 (D+), J11.B6 (D+), U9.19 (D+)
/USB-C circuit/USB_D-: J11.A7 (D-), J11.B7 (D-), U9.18 (D-)
/USB-C circuit/USB_VBUS: J11.A4_B9 (VBUS_A), J11.B4_A9 (VBUS_B), Q2.2 (G), R17.1; also elsewhere on the board
GND: C53.1, C54.1, C55.2, J11.A1_B12 (GND_A), J11.B1_A12 (GND_B), J11.SH1 (SHIELD), J11.SH2 (SHIELD), J11.SH3 (SHIELD), J11.SH4 (SHIELD), Q2.3 (S), Q3.3 (S), R15.2, R16.2, R17.2, U9.20 (VSS); also elsewhere on the board
unnamed: Q2.1 (D), Q3.2 (G), R18.2

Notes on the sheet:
Power-On-Reset circuit Fig 1-6 (p8) of MCP2200 datasheet
I think shield has to be tied to GND, but found contradicting info. SBU pins are for other purposes (HDMI,...)
Since UART can not receive & transmit at the same time, sharing R isn't a problem ?
GP6/7 are active low, so we need this config so that LED shines when RX/TX is active
LED has 2.1-2.4V voltage drop Vf and can handle 25mA max with 100R, should have ~10mA
SBU pins are for USB "alternate mode" since we don't use it, we leave them floating
Pull-up only useful for TX
CL = 18pF Cs = assumed 5pF Cl = 2*(18-5) = 26 pF 26 pF cap hard to find -> 27pF
12 MHz Oscillator
MCP2200 chip transforms USB protocol into UART for STM32 to understand
CTS and RTS not useful Other GPIO pins not useful

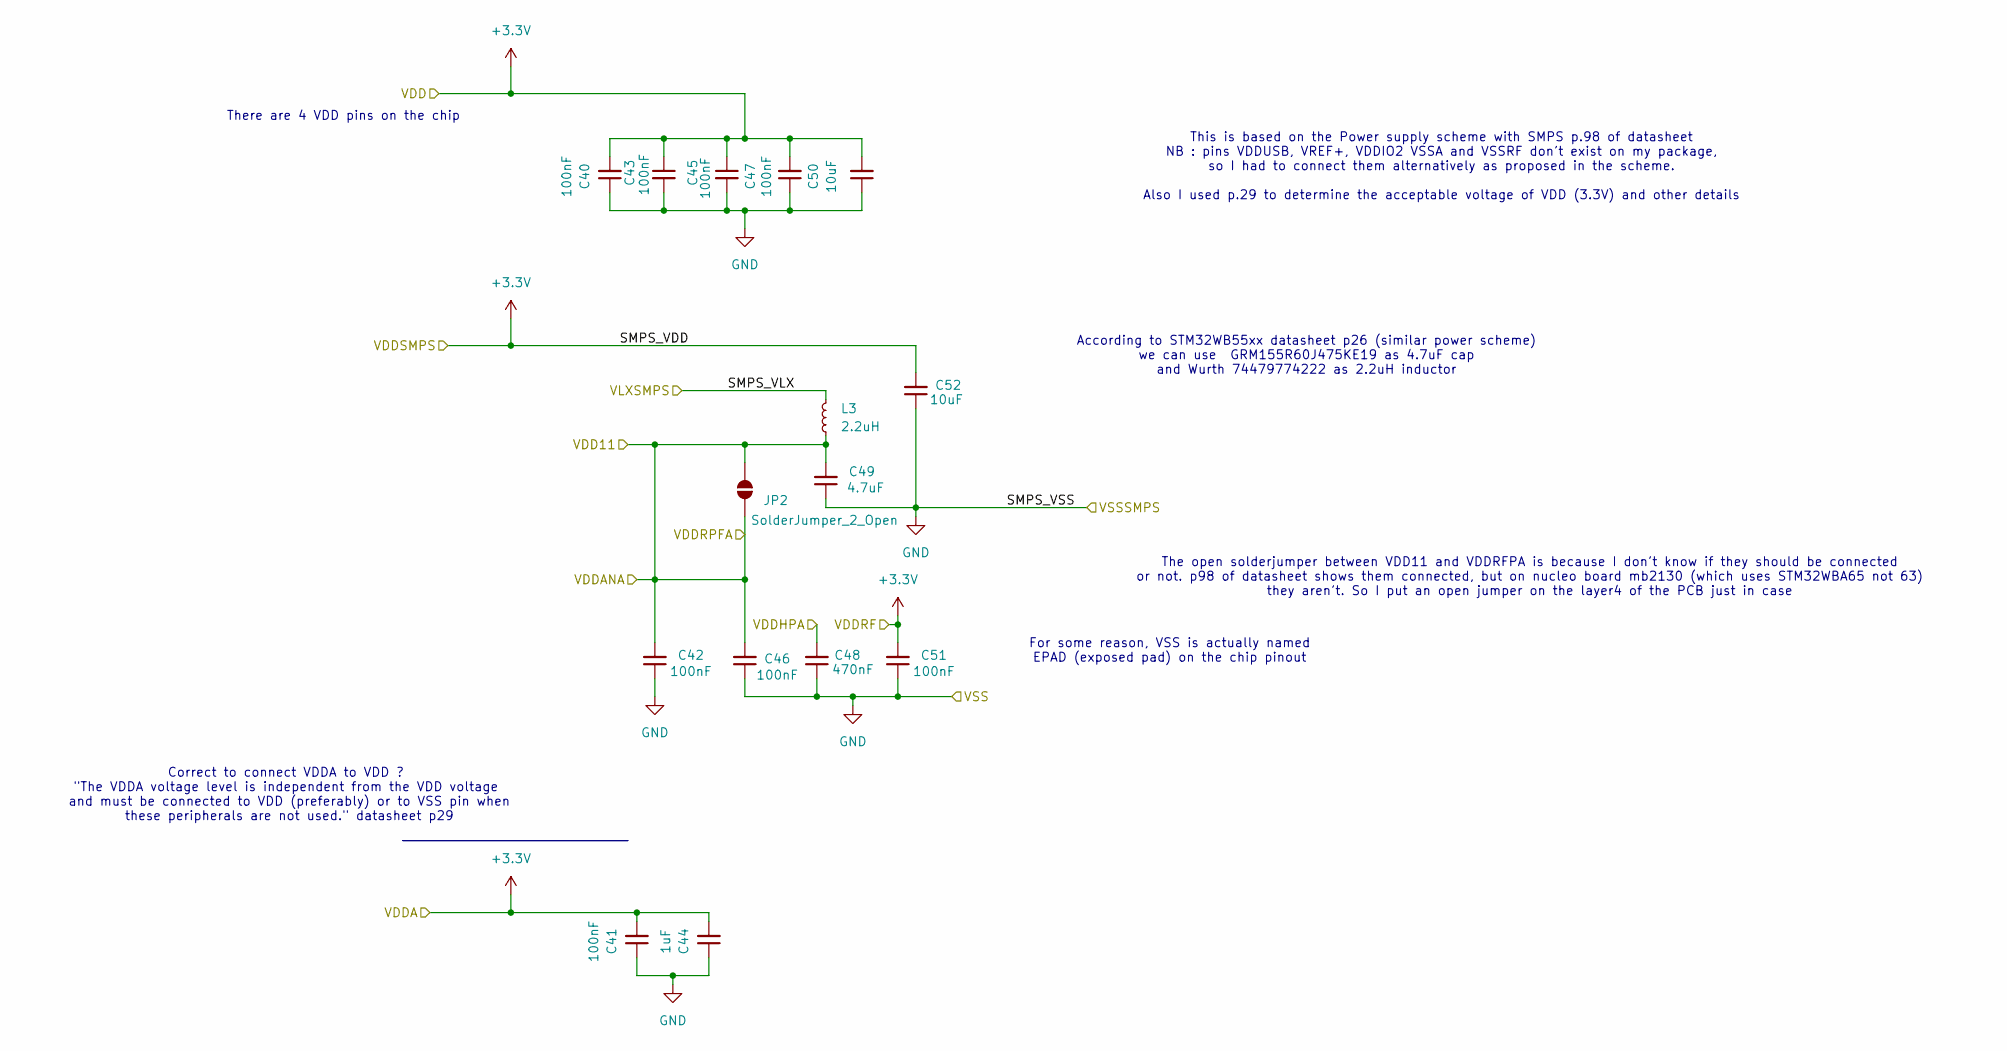
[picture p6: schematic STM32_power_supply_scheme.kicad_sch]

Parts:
C40, C41, C42, C43, C45, C46, C47, C51: 100nF; C_0201_0603Metric_Pad0.64x0.40mm_HandSolder; Manufacturer_Part_Number CL05B104KP5VPNC
C44: 1uF; C_0201_0603Metric_Pad0.64x0.40mm_HandSolder; Manufacturer_Part_Number CL05A105KP5NNNC
C48: 470nF; C_0201_0603Metric_Pad0.64x0.40mm_HandSolder; Manufacturer_Part_Number C0402C473K8RACAUTO7411
C49: 4.7uF; C_0201_0603Metric_Pad0.64x0.40mm_HandSolder; Manufacturer_Part_Number GRM155C61E475ME15D
C50, C52: 10uF; C_0201_0603Metric_Pad0.64x0.40mm_HandSolder; Manufacturer_Part_Number GRM155R61A106ME11D
JP2: SolderJumper_2_Open; SolderJumper-2_P1.3mm_Open_RoundedPad1.0x1.5mm
L3: 2.2uH; L_0805_2012Metric; Manufacturer_Part_Number 74479774222

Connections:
+3.3V: C40.2, C41.2, C43.1, C44.2, C45.1, C47.2, C50.2, C51.2, C52.2; also elsewhere on the board
/VDD11: C42.2, C46.2, C49.2, JP2.1 (A), JP2.2 (B), L3.1; also elsewhere on the board
/VDDHPA: C48.2; also elsewhere on the board
/VLXSMPS: L3.2; also elsewhere on the board
GND: C40.1, C41.1, C42.1, C43.2, C44.1, C45.2, C46.1, C47.1, C48.1, C49.1, C50.1, C51.1, C52.1; also elsewhere on the board

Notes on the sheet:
Correct to connect VDDA to VDD ? "The VDDA voltage level is independent from the VDD voltage and must be connected to VDD (preferably) or to VSS pin when these peripherals are not used." datasheet p29
There are 4 VDD pins on the chip
The open solderjumper between VDD11 and VDDRFPA is because I don't know if they should be connected or not. p98 of datasheet shows them connected, but on nucleo board mb2130 (which uses STM32WBA65 not 63) they aren't. So I put an open jumper on the layer4 of the PCB just in case
This is based on the Power supply scheme with SMPS p.98 of datasheet NB : pins VDDUSB, VREF+, VDDIO2 VSSA and VSSRF don't exist on my package, so I had to connect them alternatively as proposed in the scheme. Also I used p.29 to determine the acceptable voltage of VDD (3.3V) and other details
According to STM32WB55xx datasheet p26 (similar power scheme) we can use GRM155R60J475KE19 as 4.7uF cap and Wurth 74479774222 as 2.2uH inductor
For some reason, VSS is actually named EPAD (exposed pad) on the chip pinout

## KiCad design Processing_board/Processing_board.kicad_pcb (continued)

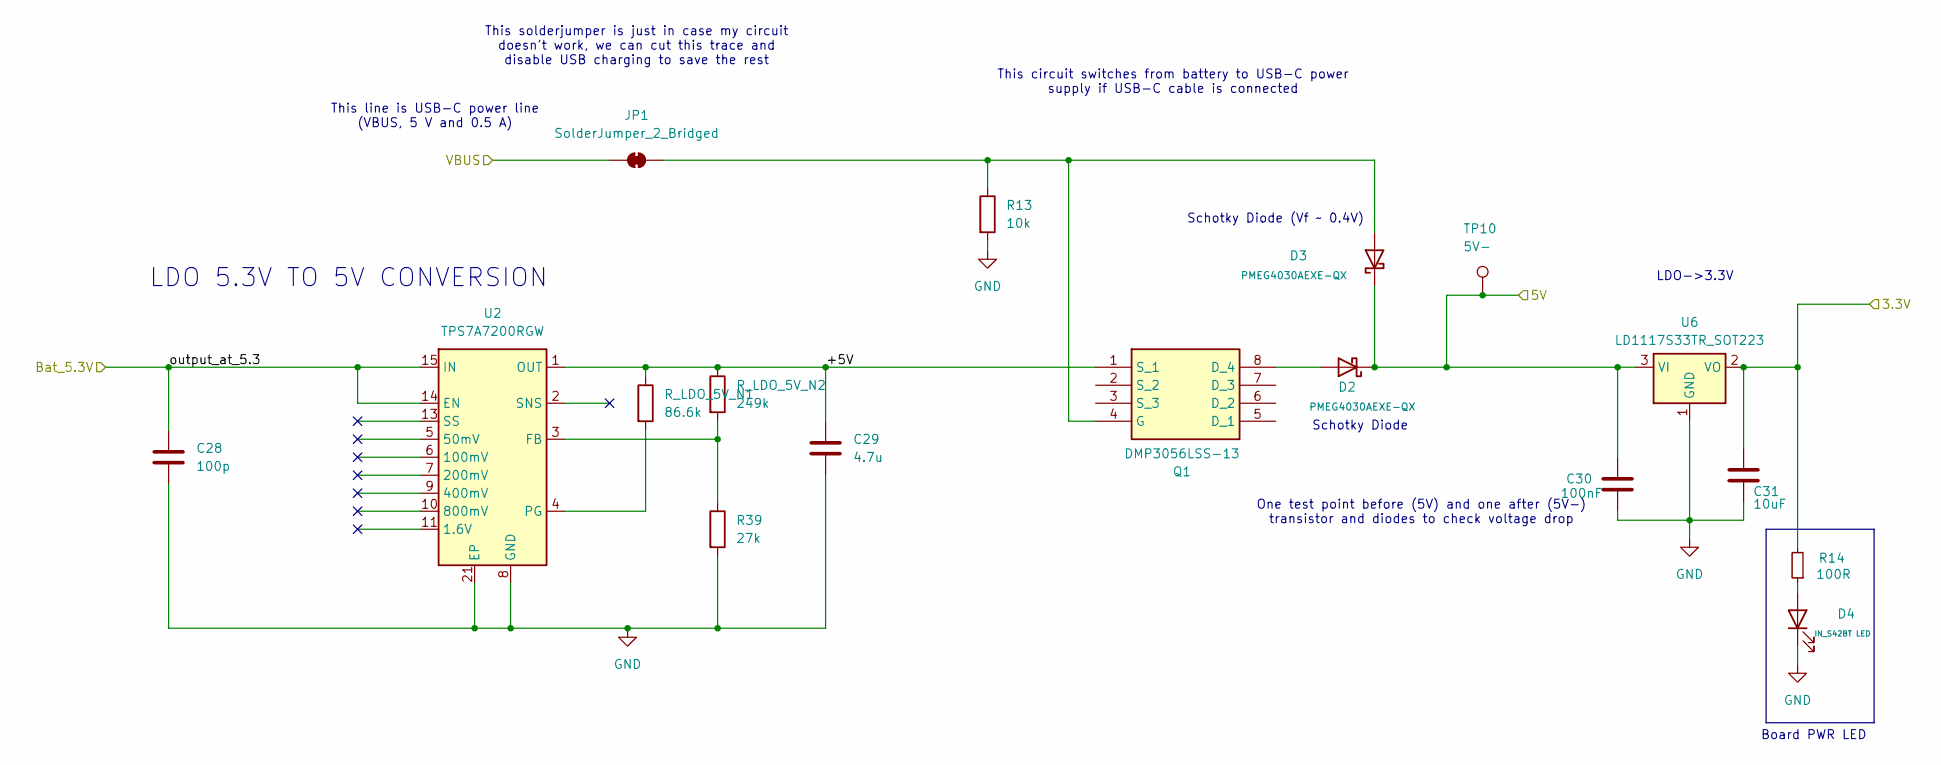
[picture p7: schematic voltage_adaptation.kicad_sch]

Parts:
C28: 100p; C_0201_0603Metric
C29: 4.7u; C_0402_1005Metric
C30: 100nF; C_0402_1005Metric; Manufacturer_Part_Number CL05B104KP5VPNC
C31: 10uF; C_0402_1005Metric; Manufacturer_Part_Number GRM155R61A106ME11D
D2, D3: PMEG4030AEXE-QX; PMEG4030AEXEQX; Manufacturer_Part_Number PMEG4030AEXE-QX
D4: IN_S42BT LED; LED_0402_1005Metric; Manufacturer_Part_Number IN-S42BT5G
JP1: SolderJumper_2_Bridged; SolderJumper-2_P1.3mm_Bridged2Bar_RoundedPad1.0x1.5mm
Q1: DMP3056LSS-13; SOIC127P600X170-8N; Mouser Part Number 621-DMP3056LSS-13
R13: 10k; R_0402_1005Metric; Manufacturer_Part_Number 560112110020
R14: 100R; R_0402_1005Metric; Manufacturer_Part_Number RK73B1ETTPD101J
R39: 27k; R_0603_1608Metric
R_LDO_5V_N1: 86.6k; C_0201_0603Metric_Pad0.64x0.40mm_HandSolder
R_LDO_5V_N2: 249k; R_0201_0603Metric
TP10: 5V-; TestPoint_Pad_D1.0mm
U2: TPS7A7200RGW; Texas_RGW0020A_VQFN-20-1EP_5x5mm_P0.65mm_EP3.15x3.15mm_Ther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
U6: LD1117S33TR_SOT223; SOT-223-3_TabPin2; Manufacturer_Part_Number LD1117S33TR

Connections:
+3.3V: C31.1, R14.2, U6.2 (VO); also elsewhere on the board
+5V: C30.1, D2.1 (K), D2.3 (K), D3.1 (K), D3.3 (K), TP10.1, U6.3 (VI); also elsewhere on the board
/Power: C28.1, U2.14 (EN), U2.15 (IN), U2.16 (IN), U2.17 (IN); also elsewhere on the board
/Power switching and voltage adaptation/+5V: C29.1, Q1.1 (S_1), R_LDO_5V_N1.1, R_LDO_5V_N2.1, U2.1 (OUT), U2.19 (OUT), U2.20 (OUT)
/USB-C circuit/USB_VBUS: JP1.1 (A); also elsewhere on the board
GND: C28.2, C29.2, C30.2, C31.2, D4.1 (K), R13.2, R39.2, U2.8 (GND), U2.18 (GND), U2.21 (EP), U6.1 (GND); also elsewhere on the board
unnamed: D2.2 (A), Q1.8 (D_4)
unnamed: D3.2 (A), JP1.2 (B), Q1.4 (G), R13.1
unnamed: D4.2 (A), R14.1
unnamed: R39.1, R_LDO_5V_N2.2, U2.3 (FB)
unnamed: R_LDO_5V_N1.2, U2.4 (PG)

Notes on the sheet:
This line is USB-C power line (VBUS, 5 V and 0.5 A)
LDO 5.3V TO 5V CONVERSION
This circuit switches from battery to USB-C power supply if USB-C cable is connected
Board PWR LED
One test point before (5V) and one after (5V-) transistor and diodes to check voltage drop
Schotky Diode
LDO->3.3V
Schotky Diode (Vf ~ 0.4V)
This solderjumper is just in case my circuit doesn't work, we can cut this trace and disable USB charging to save the rest

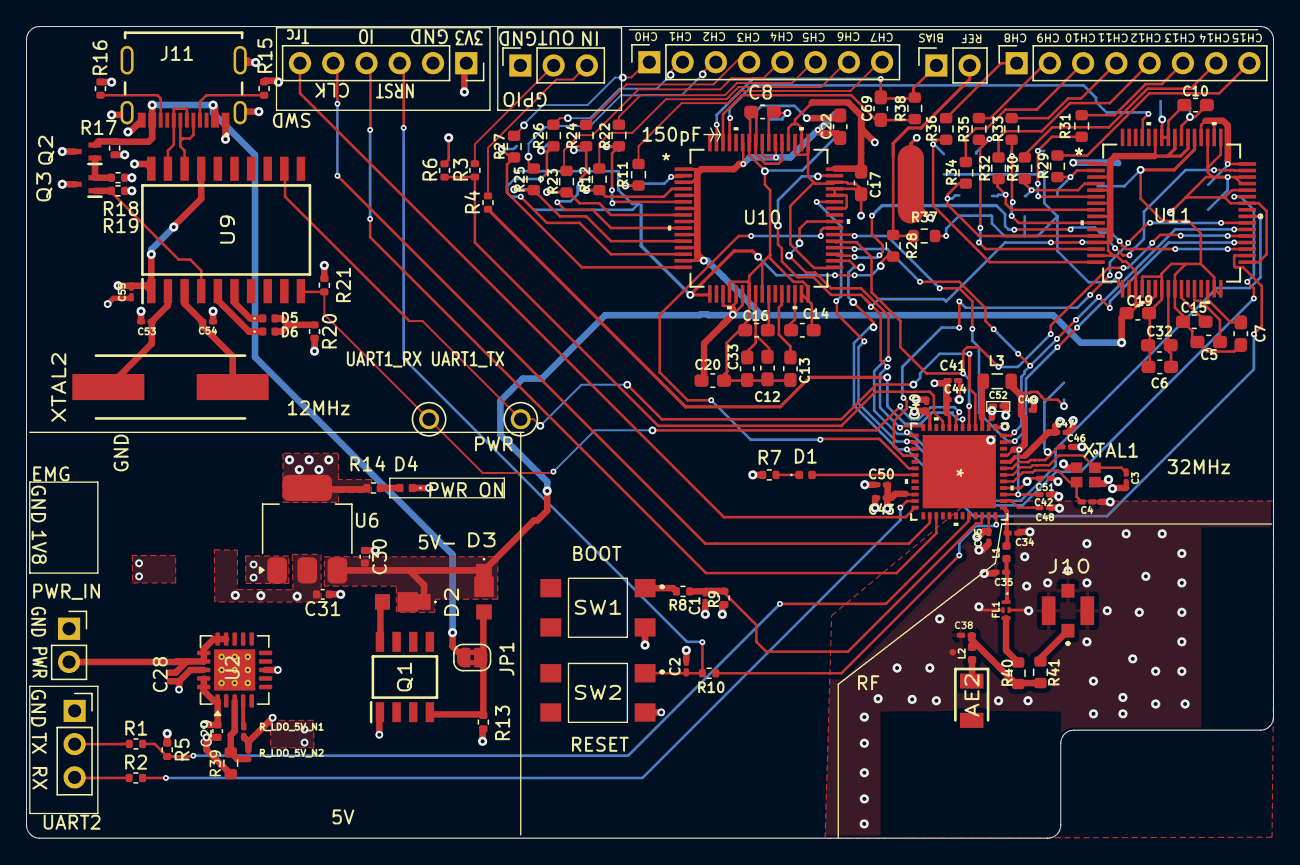
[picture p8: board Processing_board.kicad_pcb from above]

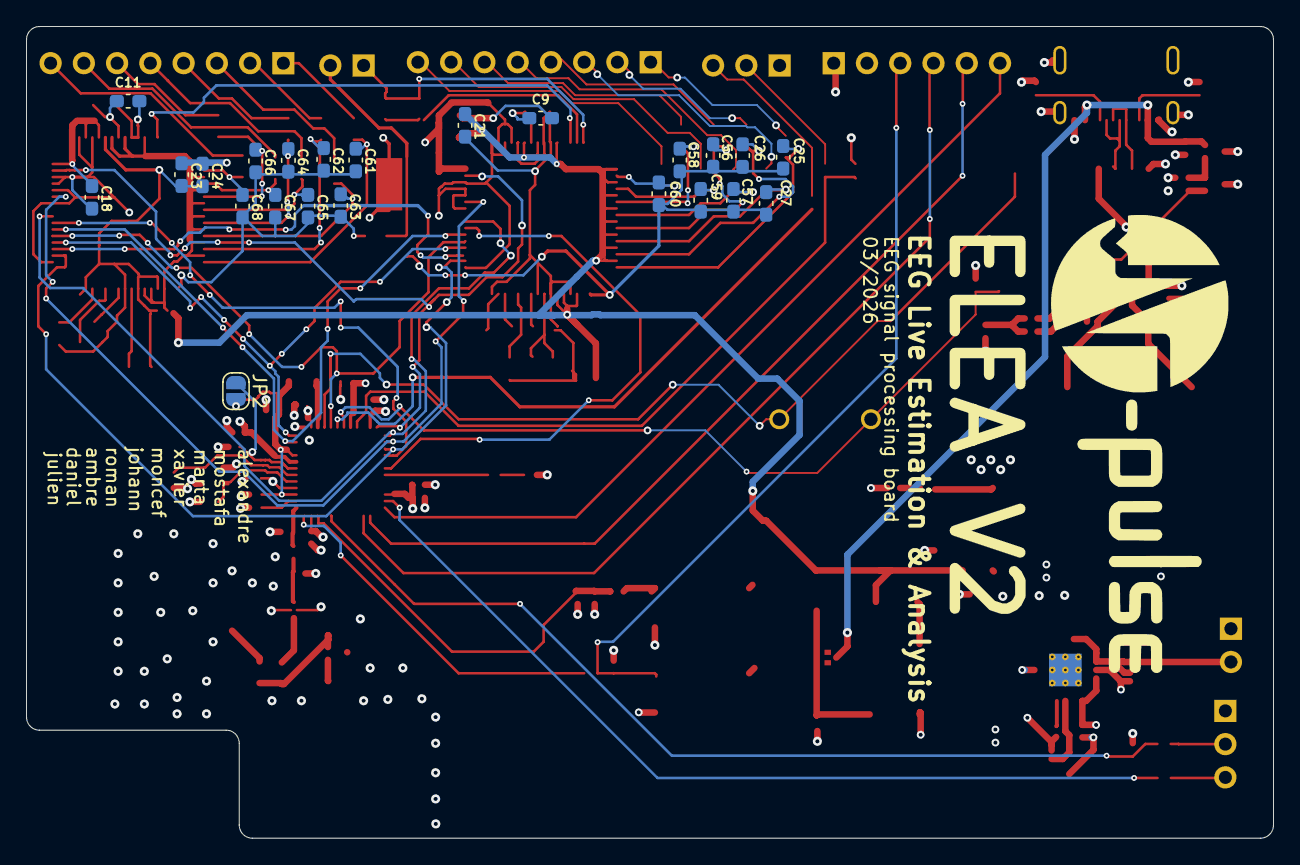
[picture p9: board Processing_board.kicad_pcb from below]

Board: 4 copper layers, 95.2 x 62.0 mm, 147 parts (23 on the bottom side), 111 nets.

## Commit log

2025-12-01 Add the new power supply and connect the ADCs at the GND an power
    [ADC.kicad_sch, Processing_board.kicad_pcb, Processing_board.kicad_sch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]
2026-03-05 RF_circuit schematic updated and board adapted
    [Processing_board.kicad_pcb, Processing_board.kicad_sch, RF.kicad_sch]
2026-03-10 Updated front silkscreen
    [Processing_board.kicad_pcb]
2026-03-16 feat: gerber files exported
    [Processing_board old.kicad_pcb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]
2026-03-19 fix, feat: fixed minor details in the silkscreen and exported gerbers
